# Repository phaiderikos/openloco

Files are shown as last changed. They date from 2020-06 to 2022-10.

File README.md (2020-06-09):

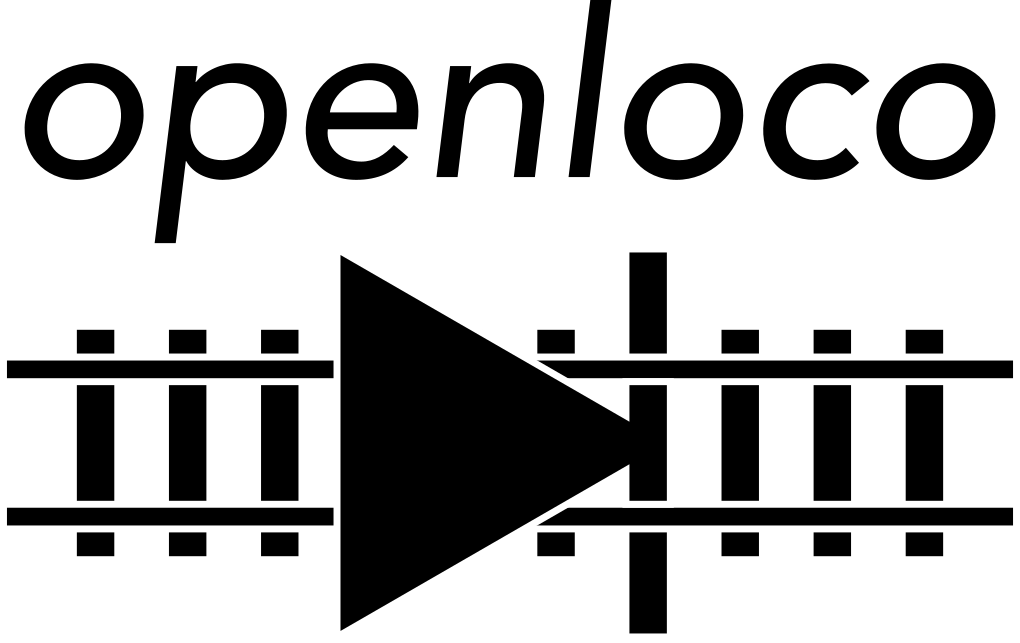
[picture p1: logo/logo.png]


> An open source and open hardware DCC decoder for locomotives.

Details.

## Getting started

A quick introduction to get it working.

### PCB

Required PCB capabilities for manifacturing.

### BOM

Table.

### Assembling

Some notes on component placement and soldering.

### Programming

Other notes on SWD.

### Wiring

Table and explanation.

## Features

* Tiny
* Open Hardware and Open Source
* Fully programmable and customizable
* other

## Configuration

Here you should write what are all of the configurations a user can enter when
using the project.

## Contributing

If you'd like to contribute, please fork the repository and use a feature
branch. Pull requests are warmly welcome.

## Links

- Project homepage: none
- Repository: https://github.com/federico1564S/openloco
- Issue tracker: https://github.com/federico1564S/openloco/issues
- Related projects:
  - 1
  - 2

## Licensing

This project is licensed under GPL3 license.

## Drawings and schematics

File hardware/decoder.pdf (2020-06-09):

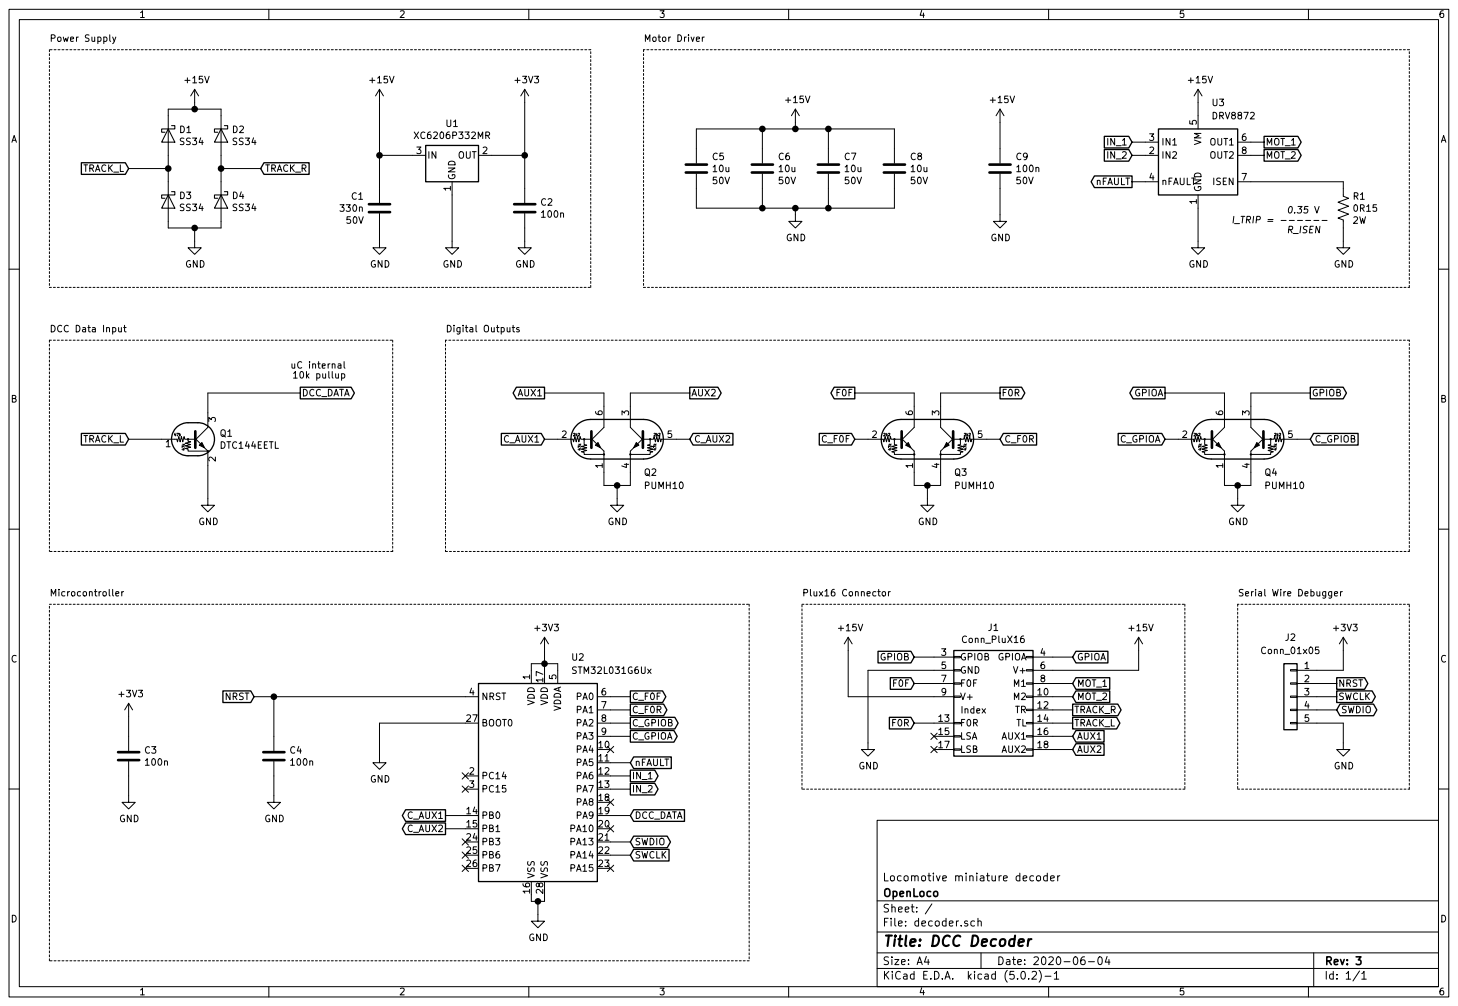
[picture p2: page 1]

5 VSS 16 VSS 28 U2STM32L031G6Ux Microcontroller Serial Wire Debugger GND Motor Driver +15V GND

Id: 1/1 Title: DCC Decoder File: decoder.sch Sheet: / OpenLoco

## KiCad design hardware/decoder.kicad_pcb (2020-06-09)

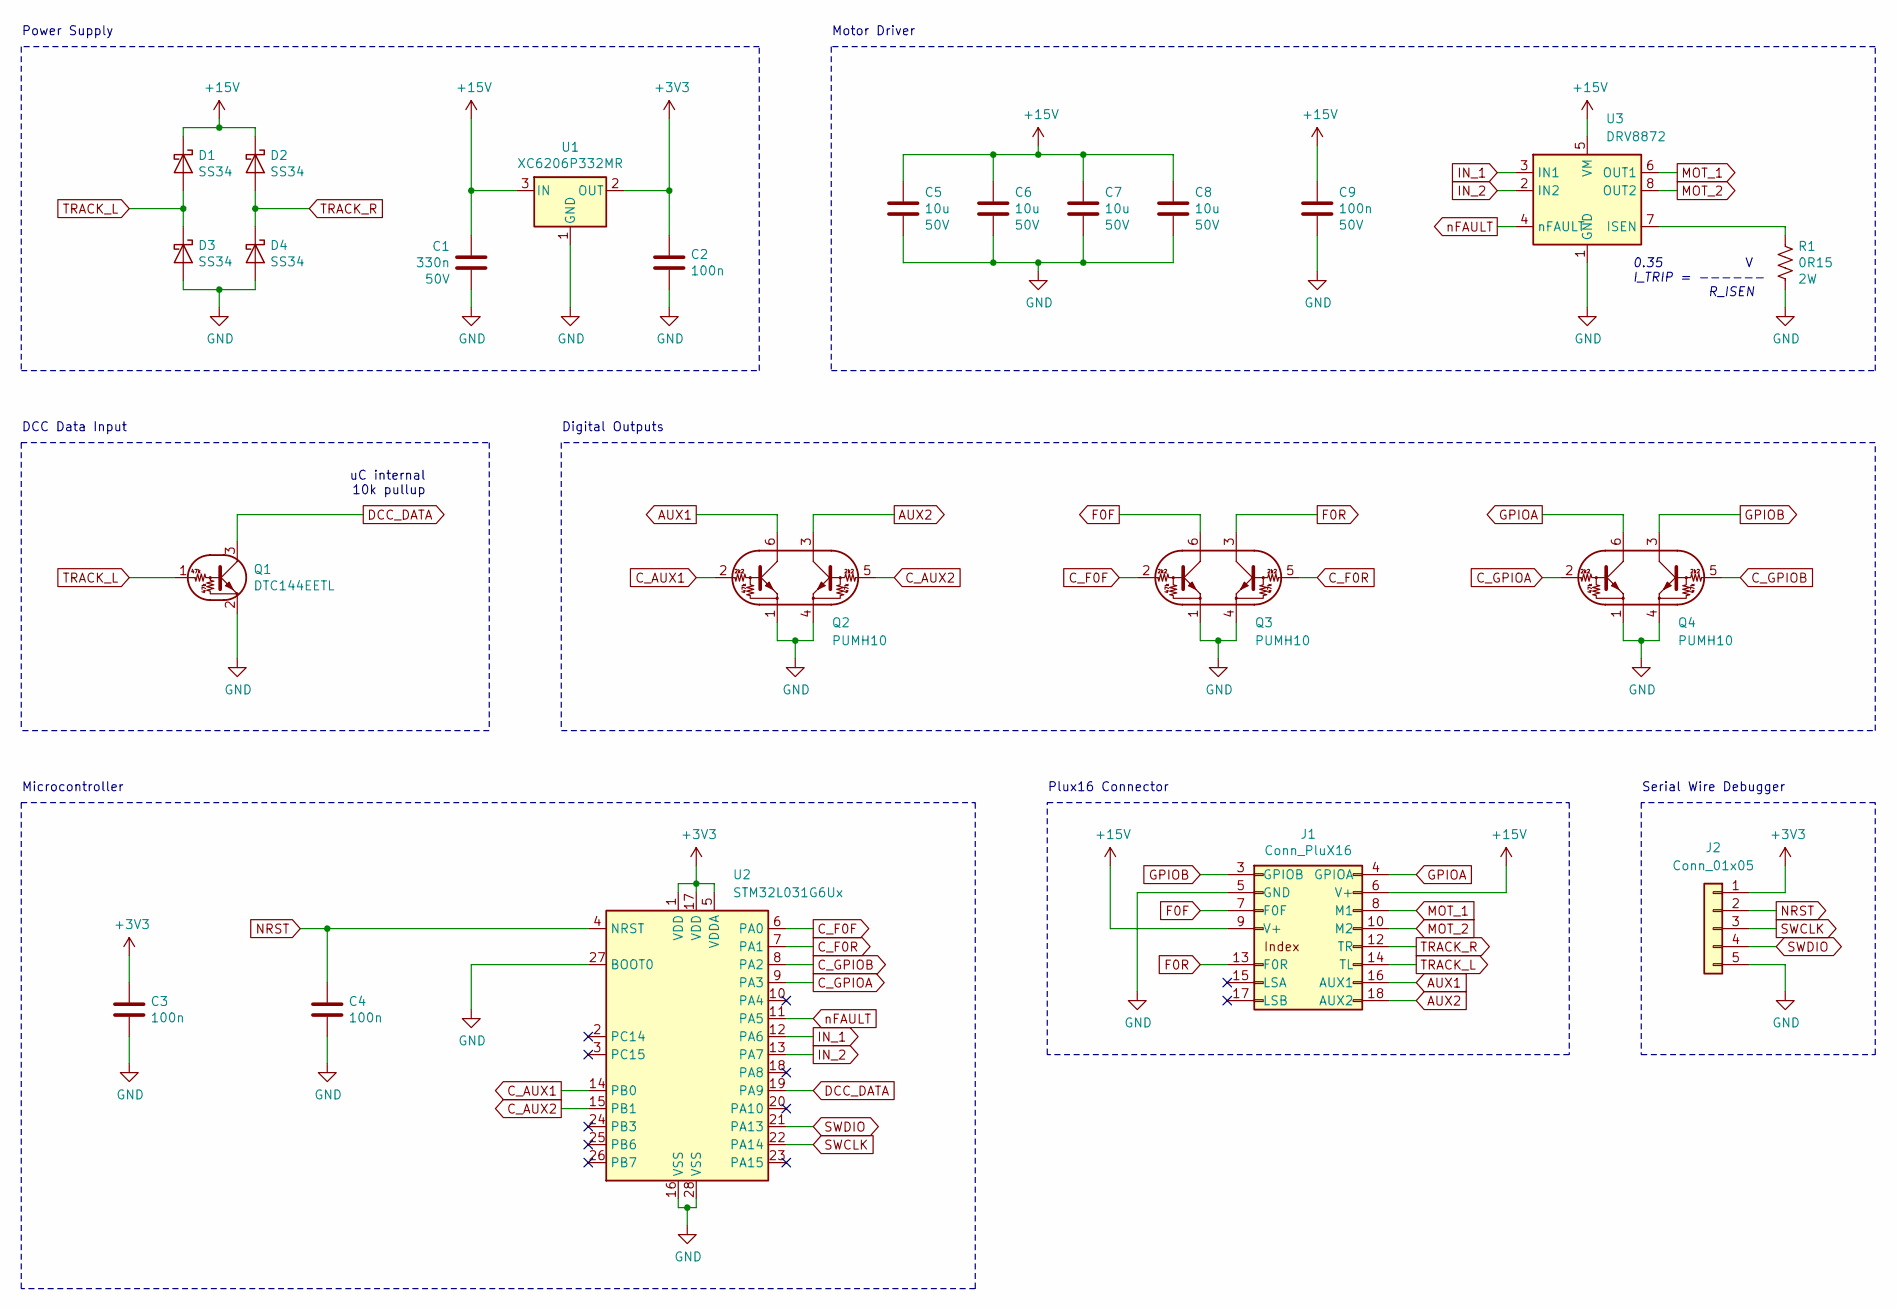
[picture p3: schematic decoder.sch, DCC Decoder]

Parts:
C1: 330n; C_1206_3216Metric
C2, C3, C4: 100n; C_0603_1608Metric
C5, C6, C7, C8: 10u; C_1206_3216Metric
C9: 100n; C_0805_2012Metric
D1, D2, D3, D4: SS34; D_SMA
J1: Conn_PluX16; PinHeader_2x08_P1.27mm_Vertical_SMD
J2: Conn_01x05; Pitch_1x05_P1.27mm
Q1: DTC144EETL; SOT-416
Q2, Q3, Q4: PUMH10; SOT-363_SC-70-6
R1: 0R15; R_2512_6332Metric
U1: XC6206P332MR; SOT-23
U2: STM32L031G6Ux; QFN-28_4x4mm_P0.5mm
U3: DRV8872; Texas_HTSOP-8-1EP_3.9x4.9mm_P1.27mm_EP2.95x4.9mm_Mask2.4x3.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

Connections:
+3V3: C2.1, C3.1, J2.1, U1.2 (OUT), U2.1 (VDD), U2.5 (VDDA), U2.17 (VDD)
+15V: C1.1, C5.1, C6.1, C7.1, C8.1, C9.1, D1.1 (K), D2.1 (K), J1.6 (V+), J1.9 (V+), U1.3 (IN), U3.5 (VM)
AUX1: J1.16 (AUX1), Q2.6 (C1)
AUX2: J1.18 (AUX2), Q2.3 (C2)
C_AUX1: Q2.2 (B1), U2.14 (PB0)
C_AUX2: Q2.5 (B2), U2.15 (PB1)
C_F0F: Q3.2 (B1), U2.6 (PA0)
C_F0R: Q3.5 (B2), U2.7 (PA1)
C_GPIOA: Q4.2 (B1), U2.9 (PA3)
C_GPIOB: Q4.5 (B2), U2.8 (PA2)
DCC_DATA: Q1.3 (C), U2.19 (PA9)
F0F: J1.7 (F0F), Q3.6 (C1)
F0R: J1.13 (F0R), Q3.3 (C2)
GND: C1.2, C2.2, C3.2, C4.2, C5.2, C6.2, C7.2, C8.2, C9.2, D3.2 (A), D4.2 (A), J1.5 (GND), J2.5, Q1.2 (E), Q2.1 (E1), Q2.4 (E2), Q3.1 (E1), Q3.4 (E2), Q4.1 (E1), Q4.4 (E2), R1.2, U1.1 (GND), U2.16 (VSS), U2.27 (BOOT0), U2.28 (VSS), U3.1 (GND), U3.9 (GND)
GPIOA: J1.4 (GPIOA), Q4.6 (C1)
GPIOB: J1.3 (GPIOB), Q4.3 (C2)
IN_1: U2.12 (PA6), U3.3 (IN1)
IN_2: U2.13 (PA7), U3.2 (IN2)
MOT_1: J1.8 (M1), U3.6 (OUT1)
MOT_2: J1.10 (M2), U3.8 (OUT2)
NRST: C4.1, J2.2, U2.4 (NRST)
unnamed: R1.1, U3.7 (ISEN)
SWCLK: J2.3, U2.22 (PA14)
SWDIO: J2.4, U2.21 (PA13)
TRACK_L: D1.2 (A), D3.1 (K), J1.14 (TL), Q1.1 (B)
TRACK_R: D2.2 (A), D4.1 (K), J1.12 (TR)
nFAULT: U2.11 (PA5), U3.4 (nFAULT)

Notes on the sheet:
DCC Data Input
Power Supply
uC internal 10k pullup
Serial Wire Debugger
Microcontroller
Motor Driver
Digital Outputs
0.35 I_TRIP = ------ R_ISEN
Plux16 Connector

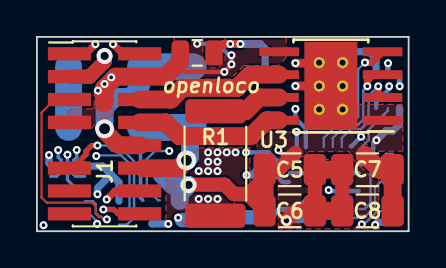
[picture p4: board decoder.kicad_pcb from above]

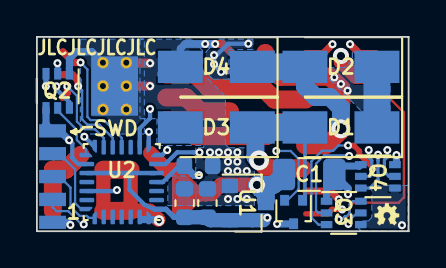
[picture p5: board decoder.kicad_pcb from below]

Board: 4 copper layers, 20.7 x 10.8 mm, 23 parts (15 on the bottom side), 27 nets.

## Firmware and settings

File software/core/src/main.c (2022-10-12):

/**
  ******************************************************************************
  * @file           : main.c
  * @brief          : Main program body
  ******************************************************************************
  * @attention
  *
  * Copyright (c) 2022 STMicroelectronics.
  * All rights reserved.
  *
  * This software is licensed under terms that can be found in the LICENSE file
  * in the root directory of this software component.
  * If no LICENSE file comes with this software, it is provided AS-IS.
  *
  ******************************************************************************
  */

#include "main.h"
#include "tim.h"
#include "gpio.h"

#include "decoder.h"

extern struct decoder dec1;

void SystemClock_Config(void);

/**
 * @brief  The application entry point.
 * @retval int
 */
int main(void)
{

	/* MCU Configuration-------------------------------------------------------- */

	/* Reset of all peripherals, Initializes the Flash interface and the Systick. */
	HAL_Init();

	/* Configure the system clock */
	SystemClock_Config();

	/* Initialize all configured peripherals */
	MX_GPIO_Init();

	MX_TIM2_Init();
	MX_TIM22_Init();

	decoder_reset(&dec1);

	HAL_TIM_Base_Start_IT(&htim2);

	while (1) {

	}
}

/**
 * @brief System Clock Configuration
 * @retval None
 */
void SystemClock_Config(void)
{
	RCC_OscInitTypeDef RCC_OscInitStruct = { 0 };
	RCC_ClkInitTypeDef RCC_ClkInitStruct = { 0 };

	/** Configure the main internal regulator output voltage
	*/
	__HAL_PWR_VOLTAGESCALING_CONFIG(PWR_REGULATOR_VOLTAGE_SCALE1);

	/** Initializes the RCC Oscillators according to the specified parameters
	* in the RCC_OscInitTypeDef structure.
	*/
	RCC_OscInitStruct.OscillatorType = RCC_OSCILLATORTYPE_HSI;
	RCC_OscInitStruct.HSIState = RCC_HSI_ON;
	RCC_OscInitStruct.HSICalibrationValue = RCC_HSICALIBRATION_DEFAULT;
	RCC_OscInitStruct.PLL.PLLState = RCC_PLL_ON;
	RCC_OscInitStruct.PLL.PLLSource = RCC_PLLSOURCE_HSI;
	RCC_OscInitStruct.PLL.PLLMUL = RCC_PLLMUL_4;
	RCC_OscInitStruct.PLL.PLLDIV = RCC_PLLDIV_2;
	if (HAL_RCC_OscConfig(&RCC_OscInitStruct) != HAL_OK) {
		Error_Handler();
	}

	/** Initializes the CPU, AHB and APB buses clocks
	*/
	RCC_ClkInitStruct.ClockType =
	    RCC_CLOCKTYPE_HCLK | RCC_CLOCKTYPE_SYSCLK | RCC_CLOCKTYPE_PCLK1 |
	    RCC_CLOCKTYPE_PCLK2;
	RCC_ClkInitStruct.SYSCLKSource = RCC_SYSCLKSOURCE_PLLCLK;
	RCC_ClkInitStruct.AHBCLKDivider = RCC_SYSCLK_DIV1;
	RCC_ClkInitStruct.APB1CLKDivider = RCC_HCLK_DIV1;
	RCC_ClkInitStruct.APB2CLKDivider = RCC_HCLK_DIV1;

	if (HAL_RCC_ClockConfig(&RCC_ClkInitStruct, FLASH_LATENCY_1) !=
	    HAL_OK) {
		Error_Handler();
	}
}

/**
 * @brief  This function is executed in case of error occurrence.
 * @retval None
 */
void Error_Handler(void)
{
	__disable_irq();
	while (1) {
	}
}

#ifdef  USE_FULL_ASSERT

/**
 * @brief  Reports the name of the source file and the source line number
 *         where the assert_param error has occurred.
 * @param  file: pointer to the source file name
 * @param  line: assert_param error line source number
 * @retval None
 */
void assert_failed(uint8_t * file, uint32_t line)
{

}
#endif	/* USE_FULL_ASSERT */

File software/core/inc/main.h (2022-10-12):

/**
  ******************************************************************************
  * @file           : main.h
  * @brief          : Header for main.c file.
  *                   This file contains the common defines of the application.
  ******************************************************************************
  * @attention
  *
  * Copyright (c) 2022 STMicroelectronics.
  * All rights reserved.
  *
  * This software is licensed under terms that can be found in the LICENSE file
  * in the root directory of this software component.
  * If no LICENSE file comes with this software, it is provided AS-IS.
  *
  ******************************************************************************
  */

#ifndef __MAIN_H
#define __MAIN_H

#ifndef STM32L031xx
#define STM32L031xx
#endif

#include "stm32l0xx_hal.h"

void Error_Handler(void);

/* Front headlight - PluX16 pin 7 */
#define C_FOF_Pin GPIO_PIN_0
#define C_FOF_GPIO_Port GPIOA
/* Rear headlight - PluX16 pin 13 */
#define C_FOR_Pin GPIO_PIN_1
#define C_FOR_GPIO_Port GPIOA
/* PluX16 pins 3 and 4*/
#define C_GPIOB_Pin GPIO_PIN_2
#define C_GPIOB_GPIO_Port GPIOA
#define C_GPIOA_Pin GPIO_PIN_3
#define C_GPIOA_GPIO_Port GPIOA
/* DRV8872 control pins */
#define nFAULT_Pin GPIO_PIN_5
#define nFAULT_GPIO_Port GPIOA
#define IN_1_Pin GPIO_PIN_6
#define IN_1_GPIO_Port GPIOA
#define IN_2_Pin GPIO_PIN_7
#define IN_2_GPIO_Port GPIOA
/* PluX16 pins 16 and 18 */
#define C_AUX1_Pin GPIO_PIN_0
#define C_AUX1_GPIO_Port GPIOB
#define C_AUX2_Pin GPIO_PIN_1
#define C_AUX2_GPIO_Port GPIOB
/* DCC signal coming from the tracks */
#define DCC_DATA_Pin GPIO_PIN_9
#define DCC_DATA_GPIO_Port GPIOA

#endif /* __MAIN_H */

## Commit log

2020-06-09 Added KiCAD project
    [decoder.kicad_pcb, decoder.sch]
2020-06-09 Corrected 3V3 pad of µC too big (caused solder bridges with next pad)
    [decoder.kicad_pcb]
